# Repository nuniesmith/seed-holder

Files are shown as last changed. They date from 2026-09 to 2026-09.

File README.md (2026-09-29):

# Sunflower seed holder

An open-top pouch that holds a **medium freezer bag of sunflower seeds** and hangs on the rim of a **bucket** with rear hooks. It is printed on an **Ender 3 Neo (220 × 220 × 250 mm)**.

**Current print checkpoint: [v0.1 first draft](src/stl/v0.1/README.md).** Print the small `hook_test.stl` first to check the bucket rim fit, then the full `pouch.stl`. Nothing has been physically tested yet.

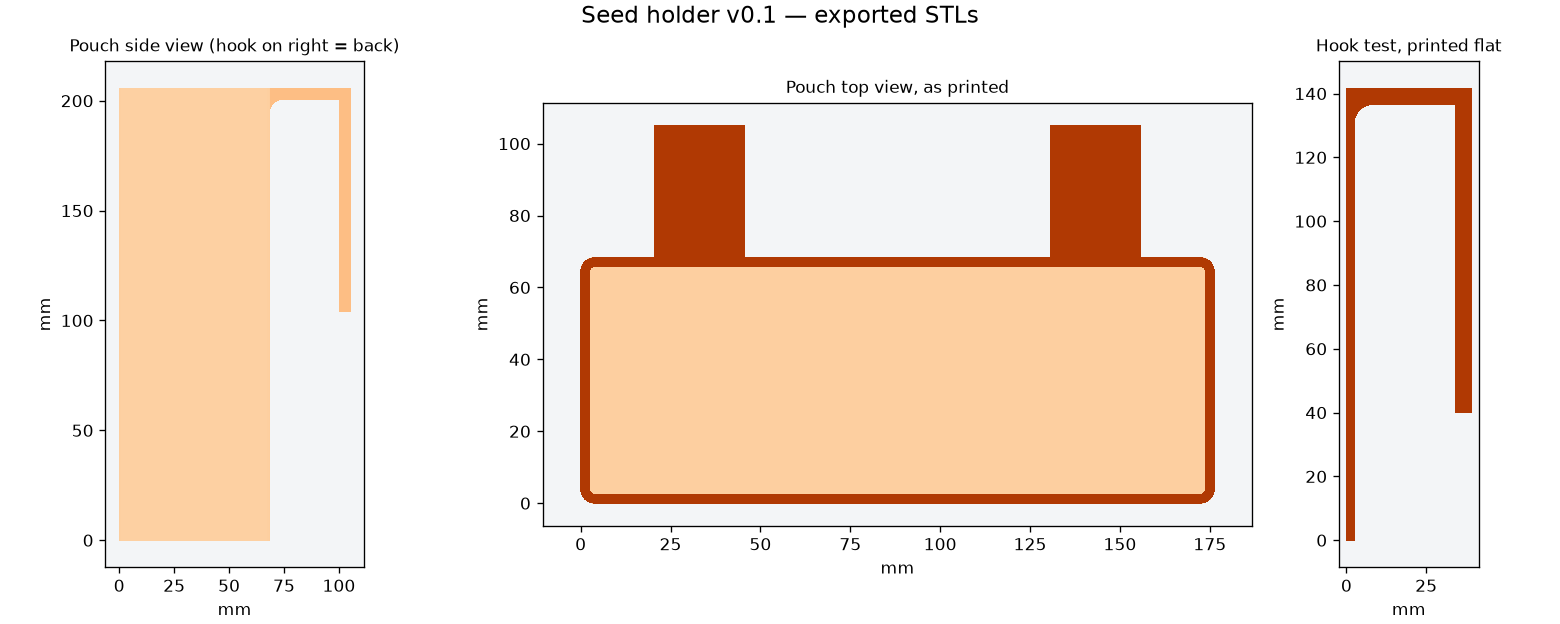
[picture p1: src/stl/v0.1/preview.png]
Side, top and hook-test views of the v0.1 STLs


## Start here

- [v0.1 print guide](src/stl/v0.1/README.md)
- [Sketch review and dimensions](docs/design-notes.md)
- [Current tasks and questions](docs/todo.md)
- [Original notebook sketch](pictures/IMG_0148.JPEG)

## Design from the sketch

| Feature | Sketch | CAD (mm) |
|---|---:|---:|
| Pouch width | 6.75 in | 171.45 inside, 176.25 outside |
| Pouch height ("L") | 8 in | 203.2 inside, 205.6 outside |
| Pouch depth | 2.5 in | 63.5 inside, 68.3 outside |
| Hook throat (gap to bucket) | 1.25 in | 31.75 |
| Hook leg length from the top | 4 in | 101.6 |

The sketch does not say whether 6.75 × 8 × 2.5 in is the inside or outside size. v0.1 treats these as **inside dimensions** so the bag gets the full space. The walls are 2.4 mm thick. See [design notes](docs/design-notes.md).

## What has been checked

Only CAD checks. Both STLs are closed, single-body meshes that fit the Ender 3 Neo's build volume ([mesh_checks.json](src/stl/v0.1/mesh_checks.json)). The bucket rim fit, bag fit, hook strength and print quality have not been tested.

## Revision history

| Directory | Role |
|---|---|
| [v0.1](src/stl/v0.1) | First draft from the notebook sketch: pouch with two rear hooks, plus a hook test piece |

## Layout

```
pictures/   reference photos and sketches
docs/       design notes, tasks
src/stl/    one folder per CAD revision (OpenSCAD source, STLs, scripts, preview)
```

Repository: [nuniesmith/seed-holder](https://github.com/nuniesmith/seed-holder).

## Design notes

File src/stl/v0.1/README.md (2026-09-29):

# v0.1 — first draft from the sketch

**Print `hook_test.stl` first.** It checks the bucket rim fit in about an hour, before you spend a full day and about 0.37 kg of filament on the pouch.

Exported STLs

## Print and test

Print at **100% scale** in the supplied orientation.

1. **hook_test.stl** — 39 × 142 × 15 mm, printed flat on its side, with no supports.
   It has one hook (31.75 mm throat, 101.6 mm leg) and a strip of back wall.
   Hang it on the bucket. Check that the rim slides in without force, that it
   doesn't rock or slip, and that the leg sits well against the other side of the wall.
   If the throat is loose or tight, change `hook_gap`; for the leg, change `hook_drop`.
2. **pouch.stl** — 176.3 × 105.1 × 205.6 mm, printed **upright, open end up**.
   It has two 25 mm wide hooks on the back. **Their legs start in mid-air, so enable
   supports under the two hook legs only**; tree supports "touching build plate"
   work best. Keep supports out of the pouch interior.
   The full walls are 2.4 mm thick (6 perimeters at 0.4 mm), so infill barely
   matters. Expect roughly 0.37 kg of PLA/PETG and a long print. Check the time in your slicer.

After printing, put in a medium freezer bag full of seeds and check:

- the bag slides in and out, and the zipper sits where you want it
- the hooks hold the loaded weight without bending
- the pouch hangs straight and doesn't swing into anything

## Parameters (`seed_holder.scad`)

| Name | Default | Meaning |
|---|---:|---|
| `inner_w`, `inner_d`, `inner_h` | 171.45, 63.5, 203.2 | Inside pouch size (6.75 × 2.5 × 8 in) |
| `wall`, `floor_t` | 2.4, 2.4 | Wall and floor thickness |
| `hook_gap` | 31.75 | Clear throat between the pouch back and the hook leg (1.25 in) |
| `hook_drop` | 101.6 | Hook leg length, measured from the top (4 in) |
| `hook_t`, `hook_w` | 5, 25 | Hook thickness and width |
| `hook_x` | [-55, 55] | Hook centers from the middle of the pouch |

The asserts reject any part that exceeds the 220 × 220 mm bed (with a 10 mm brim allowance) or 250 mm of Z.

## Reproduce

```sh
python export_models.py    # needs OpenSCAD
python validate_meshes.py  # needs NumPy; writes mesh_checks.json
python make_preview.py     # needs Matplotlib; writes preview.png
```

`mesh_checks.json` records closed oriented edges, triangle validity, one connected
body and bed/Z bounds. It does not certify strength, bag fit or bucket fit.

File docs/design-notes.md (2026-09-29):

# Design notes

## Sketch review (IMG_0148, 2026-09-29)

[The notebook page](../pictures/IMG_0148.JPEG), titled "Sunflower Seeds Holder", shows:

- **Front view:** a rectangular box labeled **6.75" W**, **8" L** (vertical, i.e. height)
  and **2.5" D**, summarized as **6.75" × 8" × 2.5"**, with the note "Pouch for medium freezer bag".
- **Side view:** the pouch with a J-hook on the back, "Attach to bucket with this hook".
  The hook top is **1.25"** across (the throat), and the leg is **4"** long.
- A small tick mark at the top center of the front edge. The owner confirmed it is **not** a
  finger notch; the simple open-top design stays.

## Interpretation used in v0.1

| Decision | v0.1 choice | Why |
|---|---|---|
| Inside or outside dimensions | Inside | The bag needs the full space; the outside grows by 4.8 mm |
| "L" | Height | The sketch draws 8" vertically on the front face |
| Hook throat | 31.75 mm clear gap | Room for a bucket wall plus the rolled rim lip |
| Hook leg | 101.6 mm from the top outer surface | Matches the side-view label |
| Number of hooks | Two, 25 mm wide, 110 mm apart | Stops the pouch rotating on the rim; uses less plastic than a full-width hook |
| Top | Open, no lid | The sketch shows none |

## Bag fit

A quart-size freezer bag is about 7 × 8 in (178 × 203 mm) when flat. Once it holds
seeds it is narrower than that, so a 6.75 in inside width should be fine. The 8 in
height puts the bag's zipper about level with the pouch top. Confirm with the actual
bag brand and size you use.

## Print orientation

The pouch is taller (205.6 mm) than it is wide, so it prints upright with the open top up.
That keeps the walls as clean perimeters, needs no bridge across the floor, and fits the
Ender 3 Neo's 250 mm Z. The trade-off is that the hook legs start in mid-air and need
support. Lying the pouch on its back would put the hooks into the bed, and lying it on
its front would make the back wall a 176 mm bridge.

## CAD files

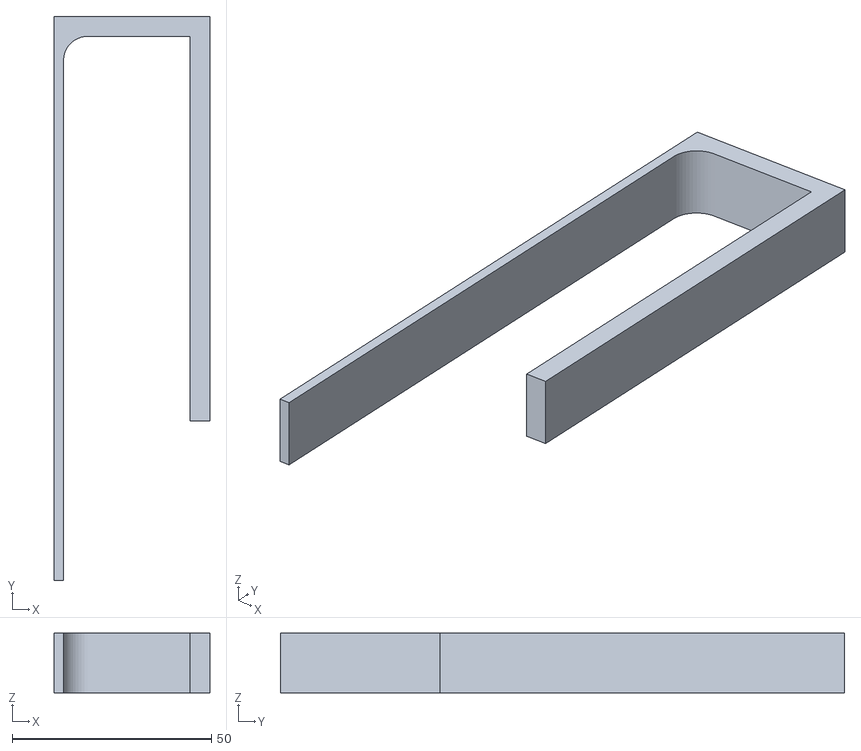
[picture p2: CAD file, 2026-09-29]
src/stl/v0.1/hook_test.stl
39.1 x 141.6 x 15.0

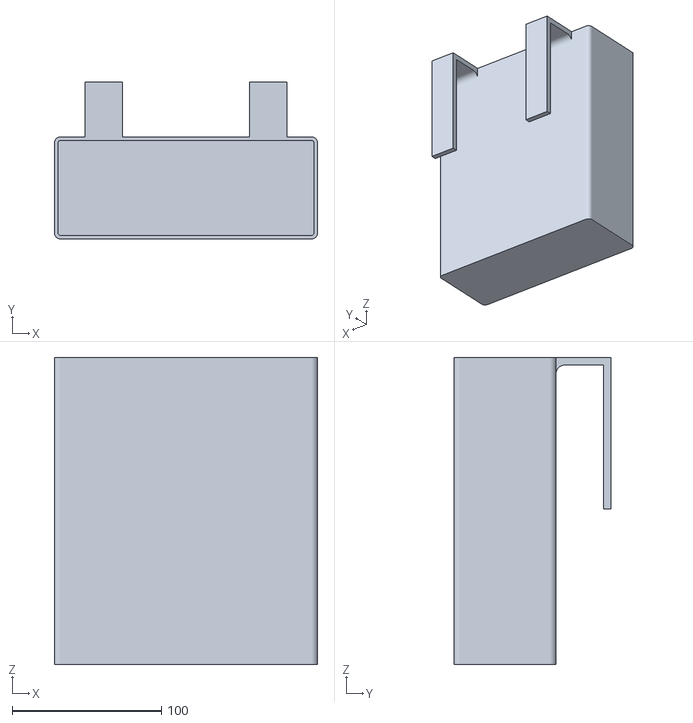
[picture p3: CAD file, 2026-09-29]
src/stl/v0.1/pouch.stl
176.2 x 105.1 x 205.6

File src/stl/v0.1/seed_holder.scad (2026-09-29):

// v0.1 sunflower seed holder: open-top pouch for a medium freezer bag,
// hung on a bucket rim by rear hooks. Source: notebook sketch IMG_0148
// (2026-09-29). Sketch dimensions are inches; everything here is mm.
// Print at 100%. See README.md for orientation and what is still unconfirmed.
part="pouch"; // pouch | hook_test
$fn=48;
in=25.4;
// Sketch: 6.75" W x 8" L x 2.5" D. Treated as INSIDE pouch size (unconfirmed).
inner_w=6.75*in;   // 171.45
inner_d=2.5*in;    // 63.5
inner_h=8*in;      // 203.2
wall=2.4;          // 6 perimeters at 0.4 mm nozzle
floor_t=2.4;
corner_r=4;        // outside vertical corners
// Side view: hook throat 1.25" wide, leg 4" long, measured from the top.
hook_gap=1.25*in;  // 31.75, clear gap between pouch back and hook leg
hook_drop=4*in;    // 101.6, top of hook to tip of leg
hook_t=5;          // bar and leg thickness
hook_w=25;         // width of each hook along the pouch
hook_x=[-55,55];   // hook centers from pouch center line
gusset=6;          // fillet block under the top bar where it meets the back wall
test_w=15;         // hook_test coupon thickness
test_wall=40;      // length of back wall kept on the coupon below the leg tip

outer_w=inner_w+2*wall;
outer_d=inner_d+2*wall;
outer_h=inner_h+floor_t;
reach=hook_gap+hook_t;
assert(outer_w+20<=220 && outer_d+reach+20<=220,"Bed footprint exceeded (Ender 3 Neo 220 x 220)");
assert(outer_h<=250,"Taller than Ender 3 Neo Z (250 mm)");
assert(hook_drop<outer_h-floor_t,"Hook leg would pass the pouch floor");
assert(hook_x[1]+hook_w/2<=outer_w/2-corner_r,"Hook runs onto rounded corner");

module rounded_box(w,d,h,r){
 hull() for(x=[r,w-r],y=[r,d-r]) translate([x,y,0]) cylinder(r=r,h=h);
}
// Hook profile in the Y-Z plane; y=0 is the outer back face, z=0 the pouch top.
module hook_profile(){
 translate([-wall/2,-hook_t]) square([reach+wall/2,hook_t]);           // top bar, overlaps wall
 translate([hook_gap,-hook_drop]) square([hook_t,hook_drop]);         // leg
 translate([0,-hook_t]) difference(){                                 // gusset
  translate([-wall/2,-gusset]) square([gusset+wall/2,gusset+1]); // +1 overlaps the bar
  translate([gusset,-gusset]) circle(r=gusset);
 }
}
module hook(){
 rotate([90,0,90]) linear_extrude(hook_w,center=true) hook_profile();
}
module pouch(){
 difference(){
  rounded_box(outer_w,outer_d,outer_h,corner_r);
  translate([wall,wall,floor_t]) rounded_box(inner_w,inner_d,outer_h,max(corner_r-wall,0.5));
 }
 for(x=hook_x) translate([outer_w/2+x,outer_d,outer_h]) hook();
}
// Flat coupon: one hook plus a strip of back wall, printed on its side.
module hook_test(){
 linear_extrude(test_w) {
  translate([0,0]) hook_profile();
  translate([-wall,-(hook_drop+test_wall)]) square([wall,hook_drop+test_wall]);
 }
}
if(part=="pouch") pouch();
else if(part=="hook_test")
 translate([wall,hook_drop+test_wall,0]) hook_test();
else assert(false,str("Unknown part: ",part));

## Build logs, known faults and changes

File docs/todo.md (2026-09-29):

# Tasks

Updated 2026-09-29. [v0.1 print guide](../src/stl/v0.1/README.md) · [Design notes](design-notes.md)

## Done

- [x] Review the notebook sketch and record its dimensions.
- [x] Model a parametric pouch with two rear J-hooks (`seed_holder.scad`).
- [x] Export `hook_test.stl` and `pouch.stl`; check that they are closed meshes within the bed and Z limits.
- [x] No finger notch: keep the simple open-top design (owner, 2026-09-29).

## Questions for the owner

- [ ] Are 6.75 × 8 × 2.5 in the **inside** or the **outside** size? v0.1 assumes inside.
- [ ] Which bucket? Measure the wall thickness and the rim lip (thickness and how far it sticks out).
- [ ] Does the pouch hang on the **outside** of the bucket or the inside? The hook works either way, but it changes what the leg rests against.
- [ ] Which bag brand and size is "medium"? Measure it flat and when filled.
- [ ] Filament: PLA or PETG? (A hot truck cab softens PLA.)

## Next print batch

- [ ] Print `hook_test.stl`; record rim fit, rocking and leg length. Adjust `hook_gap` / `hook_drop`.
- [ ] Print `pouch.stl` upright with supports under the hook legs only.
- [ ] Load it with a full bag; check bag fit, hook deflection and how it hangs.
- [ ] Record filament, nozzle, layer height and slicer profile with the results.

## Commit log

2026-09-29 Set up repo structure and v0.1 CAD from the reference photos
    Add README, docs and a parametric OpenSCAD v0.1 folder with export,
    mesh-validation and preview scripts, following the truck-gps layout.
    Claude-Session: https://claude.ai/code/session_01GspfW6RzL6x6FFXjPYGow1
    [hook_test.stl, pouch.stl, seed_holder.scad]
2026-09-29 Record owner decision: no finger notch, keep the simple design
    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
